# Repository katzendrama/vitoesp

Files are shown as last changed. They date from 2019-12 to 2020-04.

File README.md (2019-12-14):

# Viessmann Heizungen mit Loxone Steuern und das für unter 10€...

Mit diesem Gerät kann man aus Viessmann-Heizungen auslesen: 
- Abgastemperatur
- Außentemperatur
- Eingestellte Raumtemperatur
- Vorlauftemperatur
...und steuern:
- Raumtemperatur

Diese Datenpunkte werden später erweitert. 

Hardware:
- NodeMCU (reichelt: https://www.reichelt.de/nodemcu-esp8266-wifi-modul-debo-jt-esp8266-p219900.html)
- Widerstand 10 kOhm (reichelt: https://www.reichelt.de/widerstand-kohleschicht-10-kohm-axial-500-mw-5-arc-rcc050-10k-j-p237477.html?r=1)
- Widerstand 180 Ohm (reichelt: https://www.reichelt.de/widerstand-kohleschicht-180-ohm-0207-250-mw-5-1-4w-180-p1362.html?r=1)
- IR-LED 880nm 3mm (reichelt: https://www.reichelt.de/ir-led-880-nm-3-mm-t1-l-7104sf4bt-kb-p216819.html?r=1)
- IR-Fototransistor SFH 309 FA (reichelt: https://www.reichelt.de/fototransistor-npn-35v-165ma-0-165w-bedrahtet-sfh-309-fa-p60553.html?r=1)

Hinweis:
Es empfiehlt sich von den Kleinteilen mehr als nur 1 zu bestellen, denn bricht ein Beinchen ab oder ähnliches, trauert man um die paar Cent nicht... Ein passendes Netzteil hat man meist noch rumliegen, ansonsten gibt es dieses hier: https://www.reichelt.de/usb-ladegeraet-5-v-2500-ma-schwarz-microusb-otb-8012053-p263200.html?&trstct=pos_7

Software:
- Basierend auf der Bibliothek von @bertmelis https://github.com/bertmelis/VitoWiFi
- Außerdem noch auf ESP8266WiFi.h, WiFiUdp.h und natürlich der Arduino.h

Hinweis: Der String MiniserverIP funktioniert noch nicht richtig... im Code gibt es zwei Stellen, bei denen man diese ändern muss, bei WLAN und dem Port klappt das aber schon (Java ist eher meins). Die Software ist nicht schön geschrieben, das wird in späteren Versionen noch erledit.

Drumherum: 
- 3D-gedruckter V-Halter... dort kann man die Dioden per Feuerzeug oder Lötkolben einbrennen... Das wird noch verbessert... 

Programmierung:
- Dateien für Virtuelle Ausgänge / Eingänge in der Repo... In Loxone unter Vordefinierte... importieren... und IP ersetzen...

Bei Fragen bin ich über das loxforum (https://www.loxforum.com/member/8211-loxcat) erreichbar... 

Disclaimer: Keine Haftung für Schäden an Heizungsanlagen (getestet mit der Vitodens 200-W 19kW 2013)

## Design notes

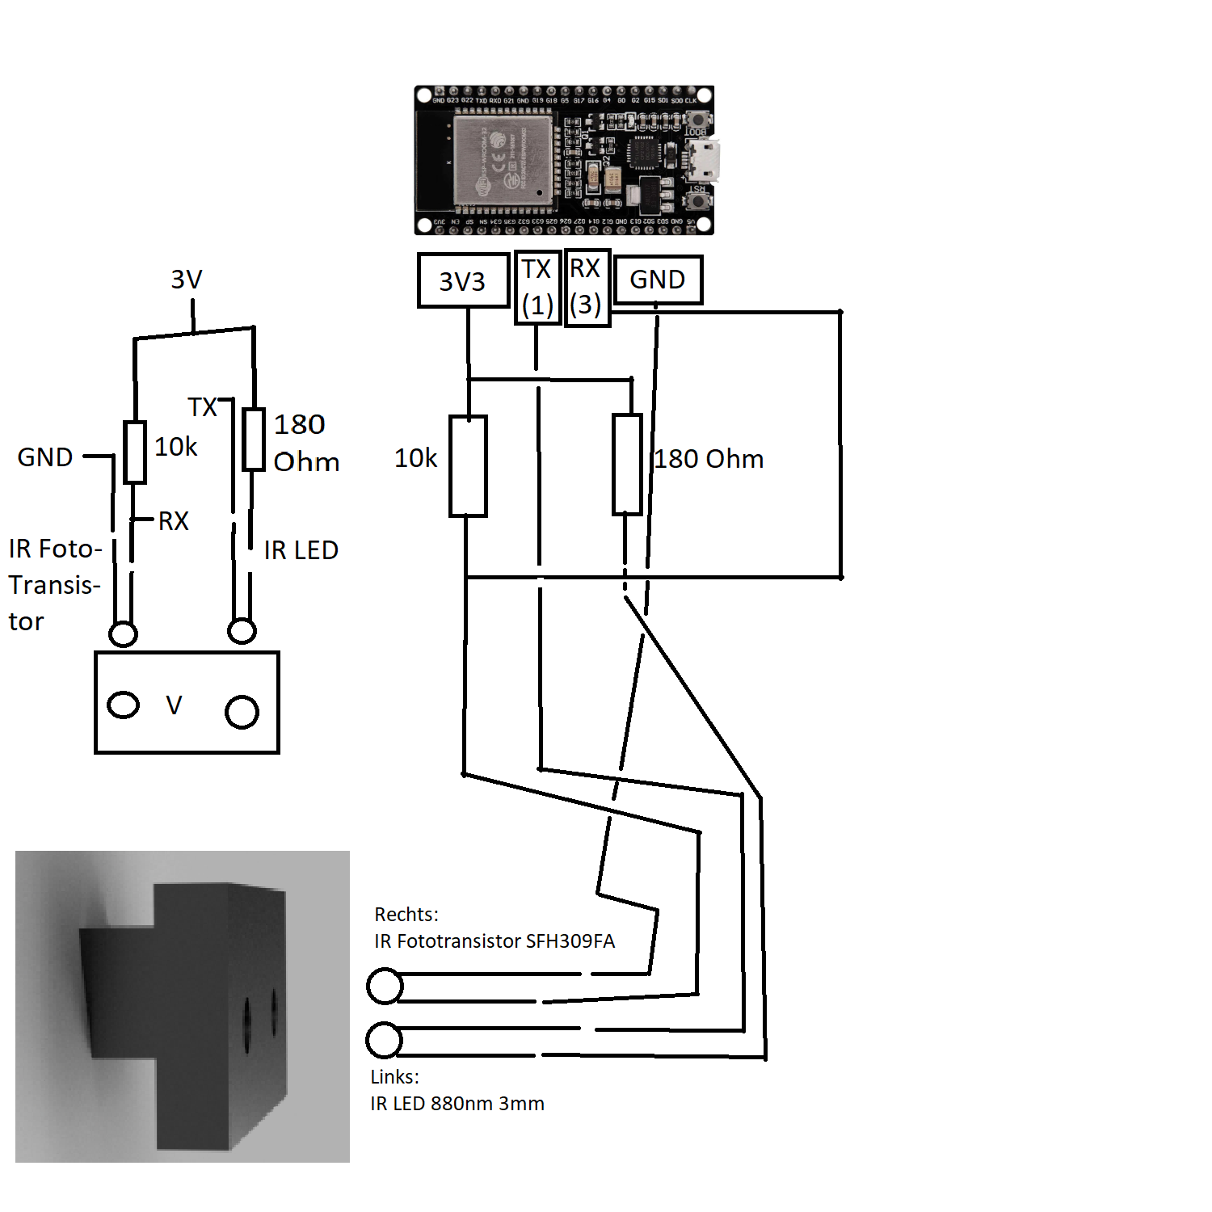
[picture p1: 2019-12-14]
Schaltplan.png

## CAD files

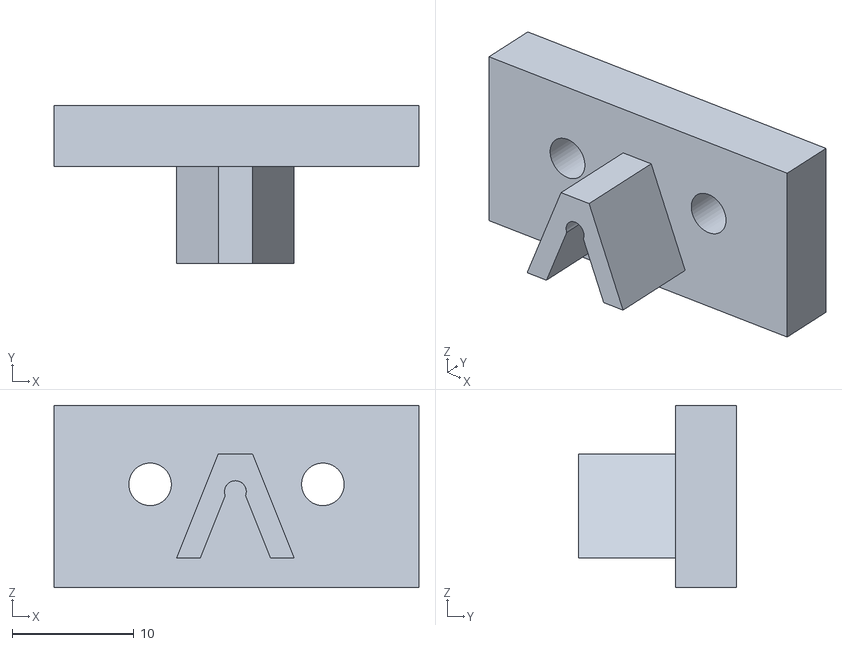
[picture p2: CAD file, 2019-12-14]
VitoESP.stl
30.0 x 13.0 x 15.0

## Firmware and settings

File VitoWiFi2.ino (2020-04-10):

#include <Arduino.h>
#include <VitoWiFi.h>
#include <ESP8266WiFi.h>
#include <WiFiUdp.h>
#include <ArduinoOTA.h>

String ssid = "HeimwehLAN";
String pass = "DiesesPasswortkenntnurdieKatze";

String MiniserverIP = "192.168.178.49";
unsigned int MiniserverPort = 3333;

float outsidetemp = 0;
float exhausttemp = 0;
float flowtemp = 0;
float roomtempset = 0;
float redroomtempset = 0;
float neigung = 0;
float niveau = 0;
float kessel = 0;
/*
float burnerstarts = 0;
float burnerhours = 0;
*/

float lastsending = 0;


WiFiUDP Udp;
unsigned int localUdpPort = 4210;
char incomingPacket[256];


VitoWiFi_setProtocol(KW);
//Außentemperatur
DPTemp outsideTemp("outsidetemp", "boiler", 0x5525);
//Abgastemperatur
DPTemp exhaustTemp("exhausttemp", "boiler", 0x0816);
//Vorlauftemperatur
DPTemp flowTemp("flowtemp", "boiler", 0x0810);
//Raumtemperatur
DPTempS roomTempSet("roomtempset", "heating", 0x2306);
//Red. Raumtemperatur
DPTempS redroomTempSet("redroomtempset", "heating", 0x2307);
//Neigung
DPTemp Neigung("neigung", "heating", 0x27D3);
//Niveau
DPTemp Niveau("niveau", "heating", 0x27D4);
//Kesseltemperatur
DPTemp Kessel("pumpe", "heating", 0x0810);
/*
//Brennerstarts
DPTemp burnerStarts("burnerstarts", "boiler", 0x088A);
//Brennerstunden
DPTemp burnerHours("burnerhours", "boiler", 0x08A7);
*/



void setup() {
  WiFi.hostname("VitoESP");
  WiFi.begin(ssid, pass);  
  //Serial.begin(115200);
  ArduinoOTA.setHostname("Viessmann-to-Loxone");
  ArduinoOTA.begin();

  //VitoWiFi.setLogger(&terminal);  // might be too verbose/fast for Blynk to handle  VitoWiFi.enableLogger();  // might be too verbose/fast for Blynk to handle
  outsideTemp.setCallback(getOutsideTemp);
  exhaustTemp.setCallback(getexhaustTemp);
  flowTemp.setCallback(getflowTemp);  
  Neigung.setCallback(getneigung);
  Niveau.setCallback(getniveau);
  Kessel.setCallback(getkessel);
  roomTempSet.setWriteable(true).setCallback(getRoomtempSet);
  redroomTempSet.setWriteable(true).setCallback(getredRoomtempSet);
  /*burnerStarts.setCallback(getburnerStarts);
  burnerHours.setCallback(getburnerhours);*/
  VitoWiFi.setGlobalCallback(globalCallbackHandler);
  VitoWiFi.setup(&Serial);

  Udp.begin(localUdpPort);
}

void loop() {
  VitoWiFi.loop();
  if(lastsending+5000 < millis()) {
    VitoWiFi.readAll();
    sendValue();
    lastsending= millis();
  }
  int packetSize = Udp.parsePacket();
  if(packetSize) {    
    // receive incoming UDP packets   
    int len = Udp.read(incomingPacket, 255);
    if (len > 0) {
      incomingPacket[len] = 0;
    }
    String input = String(incomingPacket);
    Udp.beginPacket("192.168.178.49", MiniserverPort);
    Udp.print("Empfangen: " + input);
    Udp.endPacket();    
     String recog = strtok(incomingPacket,":");
    if(recog == String("settemp")) {               
      String valuu = input.substring(8);   
      uint8_t valu = valuu.toInt();
      DPValue value(valu); 
      Udp.beginPacket("192.168.178.49", MiniserverPort);
      Udp.print("Eingestellte Innentemperatur: " + String(valuu));
      Udp.endPacket();    
      VitoWiFi.writeDatapoint(roomTempSet, value); 
      VitoWiFi.readAll();  
    } else if(recog == String("setredtemp")) {                       
      String valuu2 = input.substring(11);   
      uint8_t valu2 = valuu2.toInt();
      DPValue value(valu2); 
      Udp.beginPacket("192.168.178.49", MiniserverPort);
      Udp.print("Reduzierte Raumtemperatur: " + String(valu2));
      Udp.endPacket();    
      VitoWiFi.writeDatapoint(redroomTempSet, value); 
      VitoWiFi.readAll();  
    }   
  }
  ArduinoOTA.handle();
 }

void globalCallbackHandler(const IDatapoint& dp, DPValue value) {
  char value_str[15] = {0};
  value.getString(value_str, sizeof(value_str));
}

void getOutsideTemp(const IDatapoint& dp, DPValue value) {
  outsidetemp = value.getFloat();
}

void getexhaustTemp(const IDatapoint& dp, DPValue value) {
  exhausttemp = value.getFloat();
}

void getflowTemp(const IDatapoint& dp, DPValue value) {
  flowtemp = value.getFloat();
}

void getRoomtempSet(const IDatapoint& dp, DPValue value) {
  roomtempset = value.getU8();
}
void getredRoomtempSet(const IDatapoint& dp, DPValue value) {
  redroomtempset = value.getU8();
}
void getneigung(const IDatapoint& dp, DPValue value) {
  neigung = value.getFloat();
}
void getniveau(const IDatapoint& dp, DPValue value) {
  niveau = value.getFloat();
}
void getkessel(const IDatapoint& dp, DPValue value) {
  kessel = value.getFloat();
}


/*void getburnerStarts(const IDatapoint& dp, DPValue value) {
  burnerstarts = value.getFloat();
}

void getburnerhours(const IDatapoint& dp, DPValue value) {
  burnerhours = value.getFloat();
}*/

void sendValue() {
  VitoWiFi.readAll();   
  Udp.beginPacket("192.168.178.49", MiniserverPort);
  Udp.print("Aussentemperatur: " + String(outsidetemp));
  Udp.print("\0");
  Udp.print("Eingestellte Innentemperatur: " + String(roomtempset));
  Udp.print("\0");
  Udp.print("Abgastemperatur: " + String(exhausttemp));
  Udp.print("\0");
  Udp.print("Vorlauftemperatur: " + String(flowtemp));
  Udp.print("\0");
  Udp.print("Neigung: " + String(neigung));
  Udp.print("\0");
  Udp.print("Niveau: " + String(niveau));
  Udp.print("\0");
  Udp.print("Kesseltemperatur: " + String(kessel));
  Udp.print("\0");
  Udp.print("Reduzierte Raumtemperatur: " + String(redroomtempset));
  Udp.endPacket();
}
